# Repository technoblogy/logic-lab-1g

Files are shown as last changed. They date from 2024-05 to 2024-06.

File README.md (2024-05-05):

# Logic Lab 1G

A board that provides 12 logic gates that you can interconnect with patch cables to make a variety of different logic circuits. This version is implemented with 12 individual logic gates.

For more information see <http://www.technoblogy.com/show?4ODG>.

Alternatively see [Logic Lab](https://github.com/technoblogy/logic-lab) which is functionally identical, but implemented using an AVR microcontroller.

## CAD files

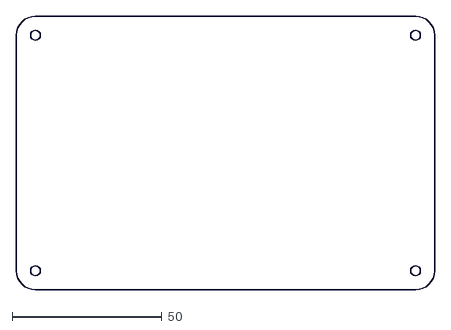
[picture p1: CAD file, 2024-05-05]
Back panel/LogicLabPanel.dxf
139.7 x 91.4

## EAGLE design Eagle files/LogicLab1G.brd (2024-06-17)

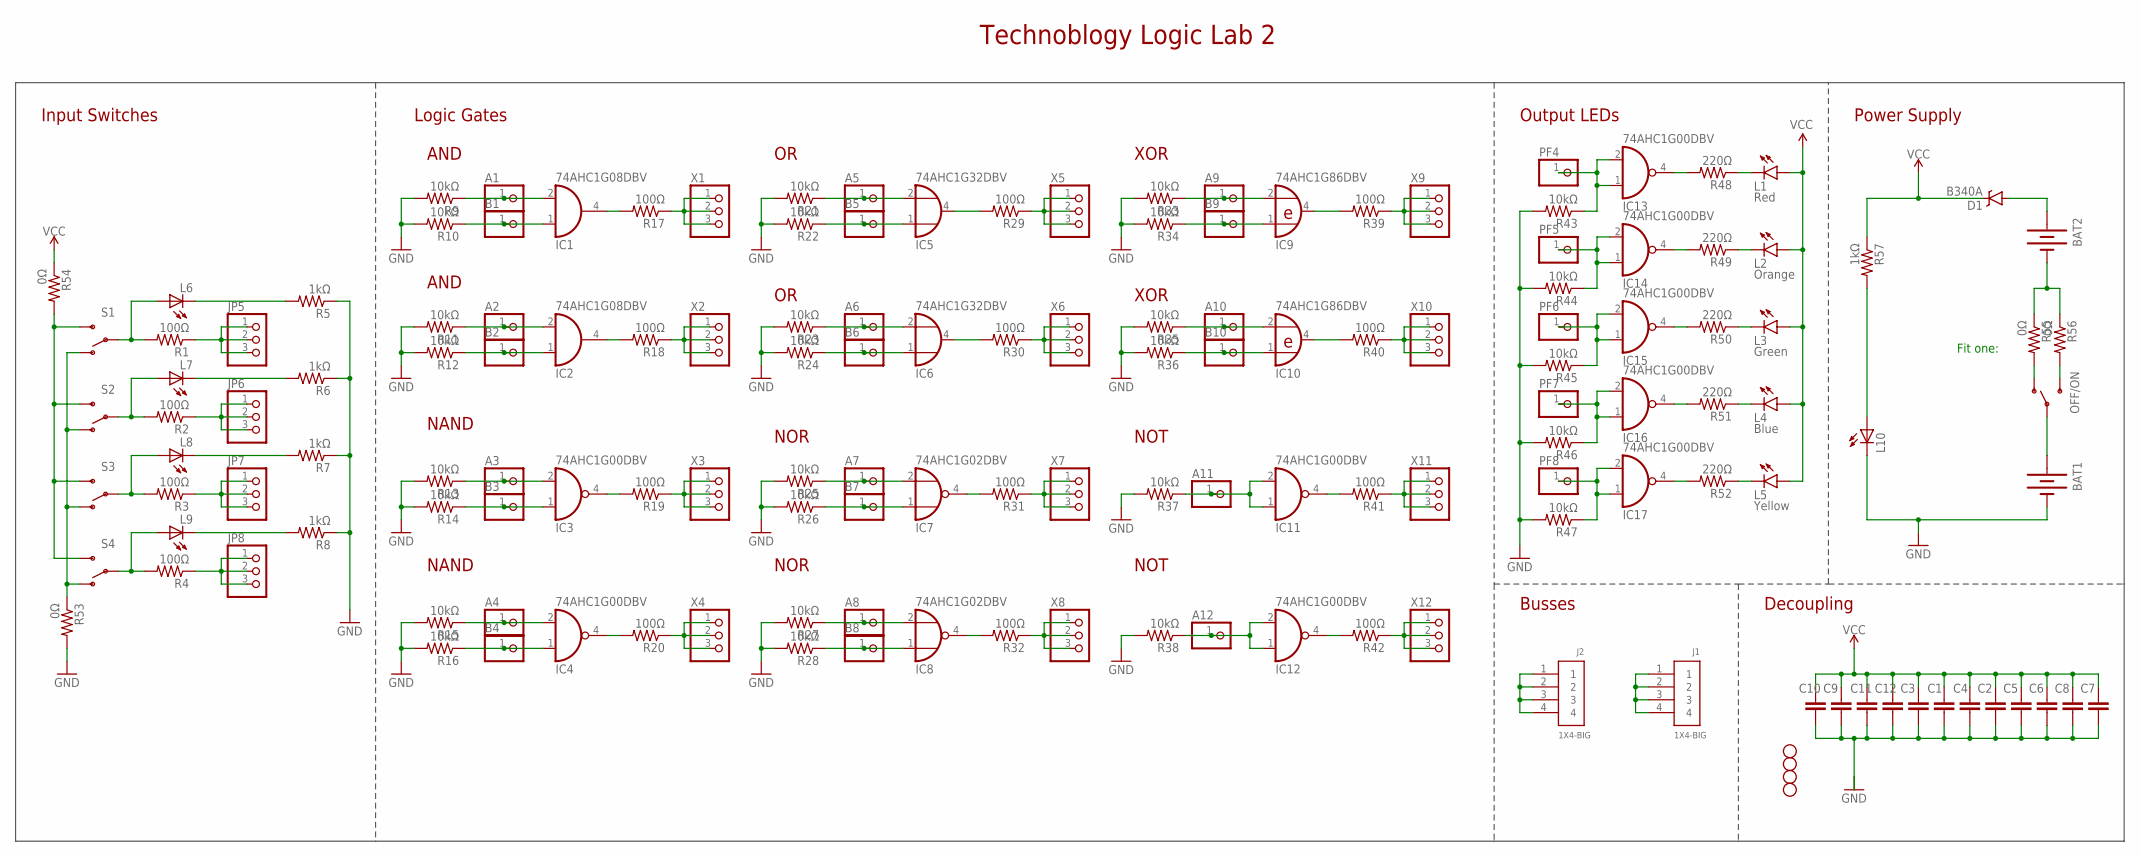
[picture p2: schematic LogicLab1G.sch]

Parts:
A1, A2, A3, A4, A5, A6, A7, A8, A9, A10, A11, A12: PINHD-1X1; 1X01
B1, B2, B3, B4, B5, B6, B7, B8, B9, B10: PINHD-1X1; 1X01
BAT1, BAT2: BATTERYAAA-KIT; BATTERY-AAA-KIT
C1, C2, C3, C5, C6, C7, C8, C9, C10, C12: 100n; 0805
C4, C11: 10uF; 0805
D1: B340A; SMA-DIODE
IC1, IC2: 74AHC1G08DBV; SOT23-5
IC3, IC4, IC11, IC12, IC13, IC14, IC15, IC16, IC17: 74AHC1G00DBV; SOT23-5
IC5, IC6: 74AHC1G32DBV; SOT23-5
IC7, IC8: 74AHC1G02DBV; SOT23-5
IC9, IC10: 74AHC1G86DBV; SOT23-5
J1, J2: 1X4-BIG; 1X04-BIG
JP1, JP2, JP3, JP4: STAND-OFF
JP5, JP6, JP7, JP8: PINHD-1X3; 1X03
L1: Red; LED5MM
L2: Orange; LED5MM
L3: Green; LED5MM
L4: Blue; LED5MM
L5: Yellow; LED5MM
L6, L7, L8, L9, L10: LEDCHIPLED_0805; CHIPLED_0805
OFF/ON: SWITCH-SPDTKIT; SWITCH-SPDT_KIT
PF4, PF5, PF6, PF7, PF8: PINHD-1X1; 1X01
R1, R2, R3, R4, R17, R18, R19, R20, R29, R30, R31, R32, R39, R40, R41, R42: 100Ω; 0805
R5, R6, R7, R8, R57: 1kΩ; 0805
R9, R10, R11, R12, R13, R14, R15, R16, R21, R22, R23, R24, R25, R26, R27, R28, R33, R34, R35, R36, R37, R38, R43, R44, R45, R46, R47: 10kΩ; 0805
R48, R49, R50, R51, R52: 220Ω; 0805
R53, R54, R55, R56: 0Ω; 0805
S1, S2, S3, S4: SWITCH-SPDTKIT; SWITCH-SPDT_KIT
X1, X2, X3, X4, X5, X6, X7, X8, X9, X10, X11, X12: PINHD-1X3; 1X03

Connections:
BOTTOMS: R53.1, S1.1 (O), S2.1 (O), S3.1 (O), S4.1 (O)
GND: BAT1.GND@1 (-), C1.2, C2.2, C3.2, C4.2, C5.2, C6.2, C7.2, C8.2, C9.2, C10.2, C11.2, C12.2, IC1.3 (GND), IC2.3 (GND), IC3.3 (GND), IC4.3 (GND), IC5.3 (GND), IC6.3 (GND), IC7.3 (GND), IC8.3 (GND), IC9.3 (GND), IC10.3 (GND), IC11.3 (GND), IC12.3 (GND), IC13.3 (GND), IC14.3 (GND), IC15.3 (GND), IC16.3 (GND), IC17.3 (GND), L10.C, R5.1, R6.1, R7.1, R8.1, R9.2, R10.2, R11.2, R12.2, R13.2, R14.2, R15.2, R16.2, R21.2, R22.2, R23.2, R24.2, R25.2, R26.2, R27.2, R28.2, R33.2, R34.2, R35.2, R36.2, R37.2, R38.2, R43.2, R44.2, R45.2, R46.2, R47.2, R53.2
unnamed: A9.1, IC9.2 (I1), R33.1
unnamed: R30.1, X6.1, X6.2, X6.3
unnamed: R29.1, X5.1, X5.2, X5.3
unnamed: B4.1, IC4.1 (I0), R16.1
unnamed: IC13.4 (O), R48.2
unnamed: IC14.4 (O), R49.2
unnamed: IC15.4 (O), R50.2
unnamed: BAT1.PWR@1 (+), OFF/ON.2
unnamed: B10.1, IC10.1 (I0), R36.1
unnamed: IC16.4 (O), R51.2
unnamed: A4.1, IC4.2 (I1), R15.1
unnamed: IC17.4 (O), R52.2
unnamed: BAT2.PWR@1 (+), D1.A
unnamed: R39.1, X9.1, X9.2, X9.3
unnamed: IC2.4 (O), R18.2
unnamed: OFF/ON.1 (O), R55.2
unnamed: R40.1, X10.1, X10.2, X10.3
unnamed: A1.1, IC1.2 (I1), R9.1
unnamed: IC5.4 (O), R29.2
unnamed: BAT2.GND@1 (-), R55.1, R56.1
unnamed: L1.K (C), R48.1
unnamed: B3.1, IC3.1 (I0), R14.1
unnamed: B1.1, IC1.1 (I0), R10.1
unnamed: B7.1, IC7.1 (I0), R26.1
unnamed: B9.1, IC9.1 (I0), R34.1
unnamed: R17.1, X1.1, X1.2, X1.3
unnamed: R41.1, X11.1, X11.2, X11.3
unnamed: OFF/ON.3 (S), R56.2
unnamed: R18.1, X2.1, X2.2, X2.3
unnamed: B2.1, IC2.1 (I0), R12.1
unnamed: A10.1, IC10.2 (I1), R35.1
unnamed: R42.1, X12.1, X12.2, X12.3
unnamed: L6.A, R1.2, S1.2
unnamed: R19.1, X3.1, X3.2, X3.3
unnamed: A8.1, IC8.2 (I1), R27.1
unnamed: R31.1, X7.1, X7.2, X7.3
unnamed: B5.1, IC5.1 (I0), R22.1
unnamed: L7.A, R2.2, S2.2
unnamed: A5.1, IC5.2 (I1), R21.1
unnamed: IC3.4 (O), R19.2
unnamed: IC9.4 (O), R39.2
unnamed: IC10.4 (O), R40.2
unnamed: IC12.4 (O), R42.2
unnamed: IC11.4 (O), R41.2
unnamed: R32.1, X8.1, X8.2, X8.3
unnamed: A11.1, IC11.1 (I0), IC11.2 (I1), R37.1
unnamed: A12.1, IC12.1 (I0), IC12.2 (I1), R38.1
unnamed: L2.K (C), R49.1
unnamed: IC6.4 (O), R30.2
unnamed: L8.A, R3.2, S3.2
unnamed: L9.A, R4.2, S4.2
unnamed: IC4.4 (O), R20.2
unnamed: R20.1, X4.1, X4.2, X4.3
unnamed: L3.K (C), R50.1
unnamed: L4.K (C), R51.1
unnamed: L5.K (C), R52.1
unnamed: IC13.1 (I0), IC13.2 (I1), PF4.1, R43.1
unnamed: IC14.1 (I0), IC14.2 (I1), PF5.1, R44.1
unnamed: JP8.1, JP8.2, JP8.3, R4.1
unnamed: JP7.1, JP7.2, JP7.3, R3.1
unnamed: L10.A, R57.2
unnamed: J2.1, J2.2, J2.3, J2.4
unnamed: JP6.1, JP6.2, JP6.3, R2.1
unnamed: L9.C, R8.2
unnamed: L8.C, R7.2
unnamed: JP5.1, JP5.2, JP5.3, R1.1
unnamed: L6.C, R5.2
unnamed: L7.C, R6.2
unnamed: B8.1, IC8.1 (I0), R28.1
unnamed: J1.1, J1.2, J1.3, J1.4
unnamed: A6.1, IC6.2 (I1), R23.1
unnamed: IC15.1 (I0), IC15.2 (I1), PF6.1, R45.1
unnamed: B6.1, IC6.1 (I0), R24.1
unnamed: A7.1, IC7.2 (I1), R25.1
unnamed: A3.1, IC3.2 (I1), R13.1
unnamed: A2.1, IC2.2 (I1), R11.1
unnamed: IC8.4 (O), R32.2
unnamed: IC7.4 (O), R31.2
unnamed: IC16.1 (I0), IC16.2 (I1), PF7.1, R46.1
unnamed: IC17.1 (I0), IC17.2 (I1), PF8.1, R47.1
unnamed: IC1.4 (O), R17.2
TOPS: R54.2, S1.3 (S), S2.3 (S), S3.3 (S), S4.3 (S)
VCC: C1.1, C2.1, C3.1, C4.1, C5.1, C6.1, C7.1, C8.1, C9.1, C10.1, C11.1, C12.1, D1.C, IC1.5 (VCC), IC2.5 (VCC), IC3.5 (VCC), IC4.5 (VCC), IC5.5 (VCC), IC6.5 (VCC), IC7.5 (VCC), IC8.5 (VCC), IC9.5 (VCC), IC10.5 (VCC), IC11.5 (VCC), IC12.5 (VCC), IC13.5 (VCC), IC14.5 (VCC), IC15.5 (VCC), IC16.5 (VCC), IC17.5 (VCC), L1.A, L2.A, L3.A, L4.A, L5.A, R54.1, R57.1

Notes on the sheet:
Technoblogy Logic Lab 2
Input Switches
Logic Gates
Output LEDs
Power Supply
AND
Busses
NAND
NOR
NOT
XOR
Decoupling
Fit one:

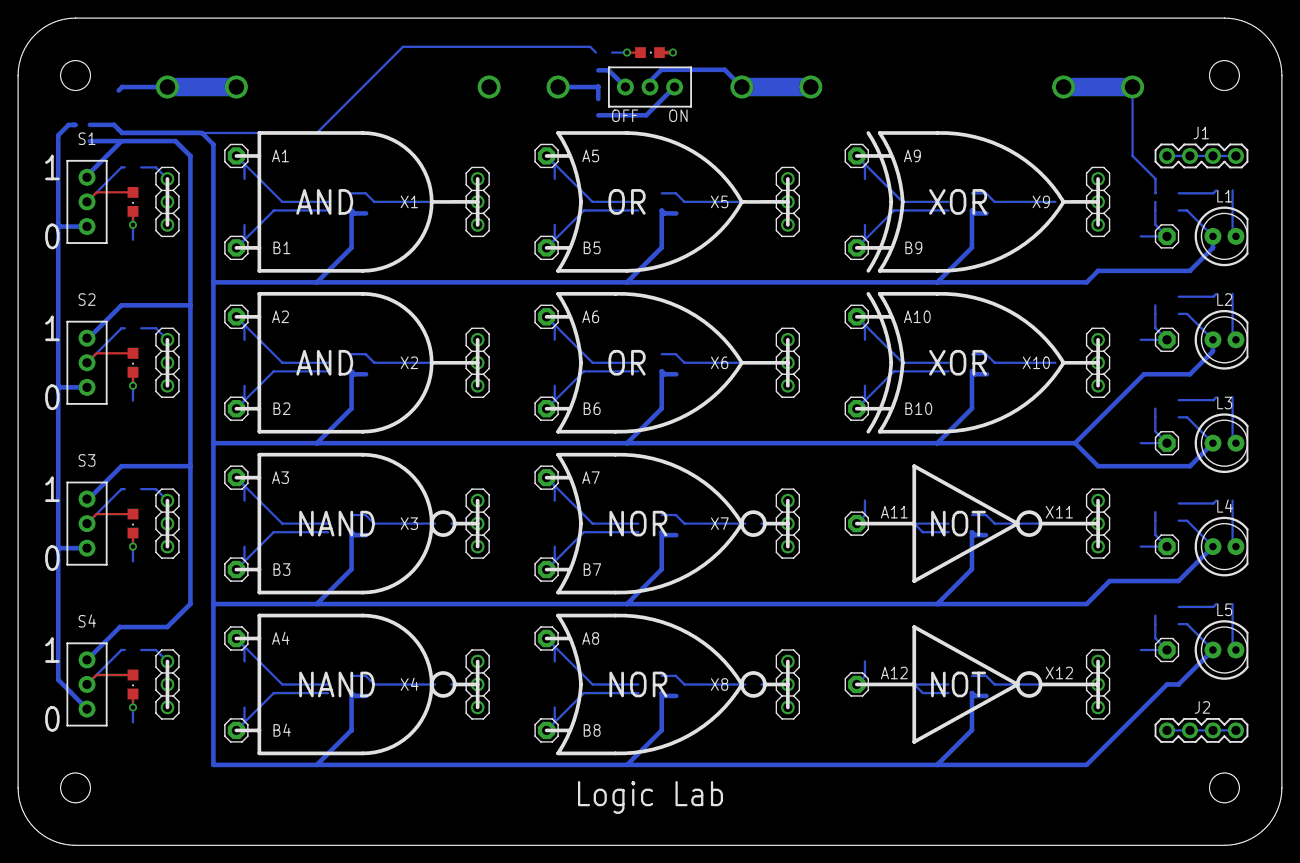
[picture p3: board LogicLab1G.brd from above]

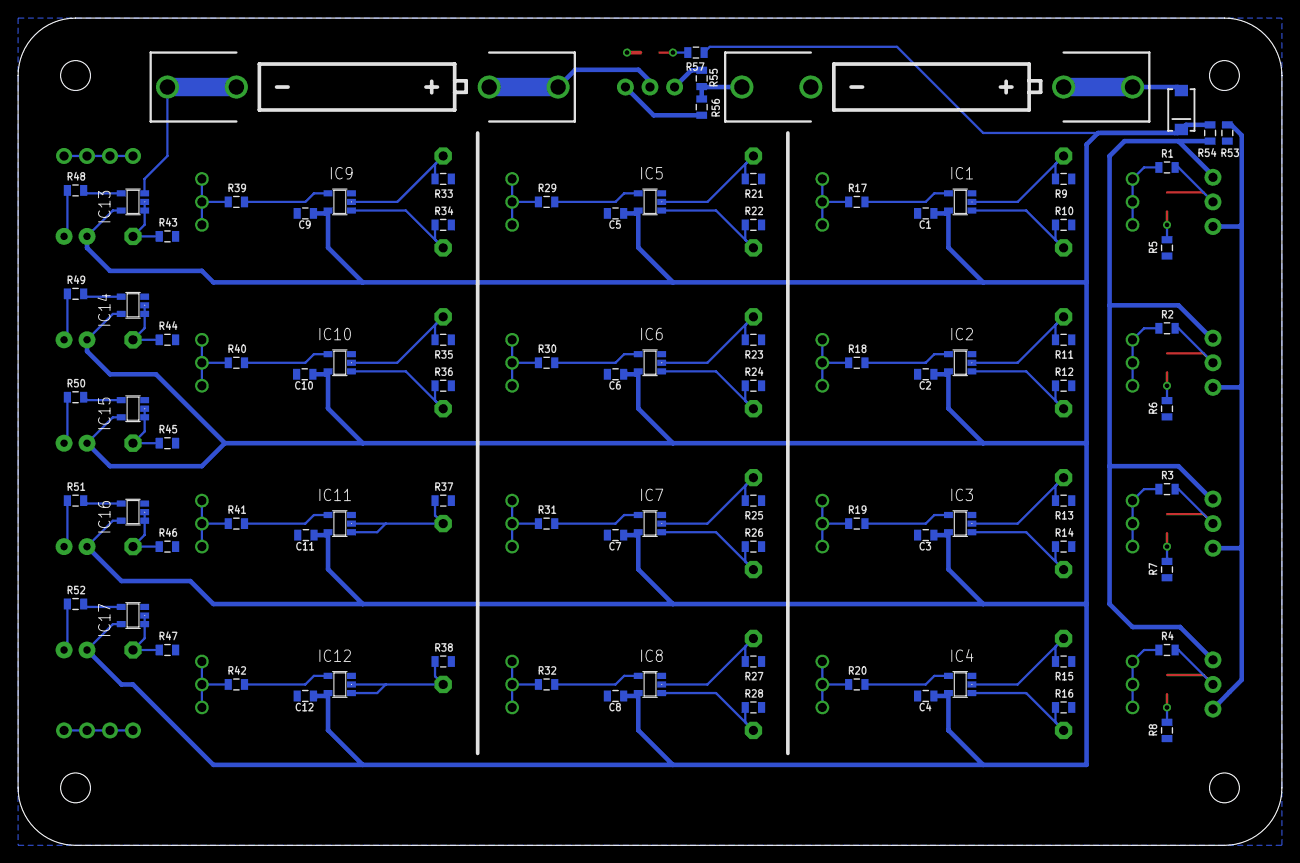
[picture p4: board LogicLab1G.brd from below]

Board: 2 copper layers, 139.7 x 91.4 mm, 153 parts (89 on the bottom side), 85 nets.

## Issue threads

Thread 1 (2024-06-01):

BOM List

dl1ekm, 2024-06-01:
Hi,
super project! I want to try to use this in our school for education. So I need some more PCBs. To order them in China is not a big deal - but I want to order also an assembly and soldering.  Therefore I need a BOM accepted by JLCPCB etc. Because I have no Eagle and the size is to big for the free edition - can you please add one?
Thanks!

technoblogy, 2024-06-01:
There is a parts list - is that not sufficient?

dl1ekm, 2024-06-02:
Well, they require a special format. For JLCPCB see the requested format here:
https://jlcpcb.com/help/article/45-Bill-of-Materials(BOM)-File-for-PCB-Assembly
To generate this from EAGLE see here:
https://jlcpcb.com/help/article/82-How-to-generate-BOM-and-CPL-from-Eagle-CAD-automatically

Would be very helpful because creating this manually is a pain and could create errors :-)
Thanks a lot!

technoblogy, 2024-06-02:
It's great that you want to use this in your school, but the project isn't really set up for PCB Assembly, and it would be a lot of work to do that.

dl1ekm, 2024-06-02:
Ok...
Well - finally it's very easy. Just add the BOM (extracted from EAGLE) to the order like the Gerber File. Especially for all the SMD parts on the backside this is great. The "normal" parts (LEDs, headers, switches) I will do myself - here the assembly would be to expensive :-)
I just checked - they have all the locic ICs in stock ready for assembly and for a very small price (just cents).

So without the EAGLE export I have to create the BOM for the SMD parts manually finally. I'll keep you updated :-)

technoblogy, 2024-06-02:
Look forward to hearing how you get on. Send me a photo!

dl1ekm, 2024-06-16:
Hi, I installed EAGLE and created the BOM for the assembly. But in your schematic you set all logic gates to the same value: 74AHC1G00DBV - so all are the same gates....
I can change this manually here - but would be great if you correct this in your repo.

technoblogy, 2024-06-16:
The only suitable Eagle part I could find was for the 74AHC1G00, and I'm not sure how to change it on the schematic. If you can tell me how to do it I'll have a go.

dl1ekm, 2024-06-16:
Hi, they are all there. Click in the Schematic on "replace" and search for 74AHC*
I finally created the BOM and changed it with a text editor (now all ready for ording at JLCPCB), because after replace I was not able to put the parts back on the board due to "free edition" limitation.

technoblogy, 2024-06-16:
OK, thanks, I'll try it tomorrow, David.

technoblogy, 2024-06-17:
OK, thanks, I've corrected the part numbers of the logic gates. Note that I've left the inverters as 74AHC1G00DBV so they are drawn with two inputs, to allow you to use a 74AHC1G00DBV instead.

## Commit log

2024-05-05 Version 1 - 5th May 2024
    [LogicLab1G.brd, LogicLab1G.sch, LogicLabPanel.dxf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]
2024-06-17 Version 1a - 17th June 2024
    Corrected the part numbers of the logic gates.
    [LogicLab1G.brd, LogicLab1G.sch]

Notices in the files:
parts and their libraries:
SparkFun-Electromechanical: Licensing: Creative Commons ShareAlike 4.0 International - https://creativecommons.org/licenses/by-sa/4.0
